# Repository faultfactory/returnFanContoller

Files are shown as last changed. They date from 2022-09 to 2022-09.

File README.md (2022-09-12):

# returnFanContoller

### Problem: 

My house has an issue with stratification in the summer, requiring us to leave a fan in the stairwell. I saw this potentially coming from talking to my neighbors and in addition to good insulation on the roof deck, I also installed a return air duct on the 2nd floor (which it did not have).  This duct is very high in the room and with a proper draw should evacuate hot air in the room quickly with the right amount of negative pressure applied. Because the return ducts in the house start with a (very poorly sealed) run of panning through joist bays and the duct takes a circuitous path upstairs, I am confident I am getting very little, if any draw from the return duct I connected to the 2nd floor.  To remedy this I have purchased a [Fantech ProAir EC-6](https://shop.fantech.net/en-US/prioair--6--ec--inline--duct--fan/p96222#!) I chose this because I would rather not play around with dampers if I can help it.  My furnace is not intended to integrate  with any sort of external fan, nor is my thermostat (nest... maybe 2nd gen?). 

### Goals: 

1. Log the activity of the 24VAC thermostat signals coming from the Nest. Also log the blower fan speeds and some relevant temperatures. 
2. Activate the booster fan when the furnace fan runs.
3. Monitor a temp sensor on the second floor and activate both the furnace and booster fan when the temperature differential exceeds a threshold. 

~~This repostitory consists of the code for the controller which will run on a raspberry pi. Schematics / BOM  will be on a separate hackaday.io project when time permits.~~

This project has been completed and I am in the process of documenting it. Overwhelming success. However, it was exceptionally difficult to get a proper PWM generated out of the raspberry pi and over time it just became more trouble than it was worth to stay with that platform. I've moved the effort to an Arduino which worked fine. I am still going to attempt to add some of the bells and whistles I wanted earlier but for now it works great.

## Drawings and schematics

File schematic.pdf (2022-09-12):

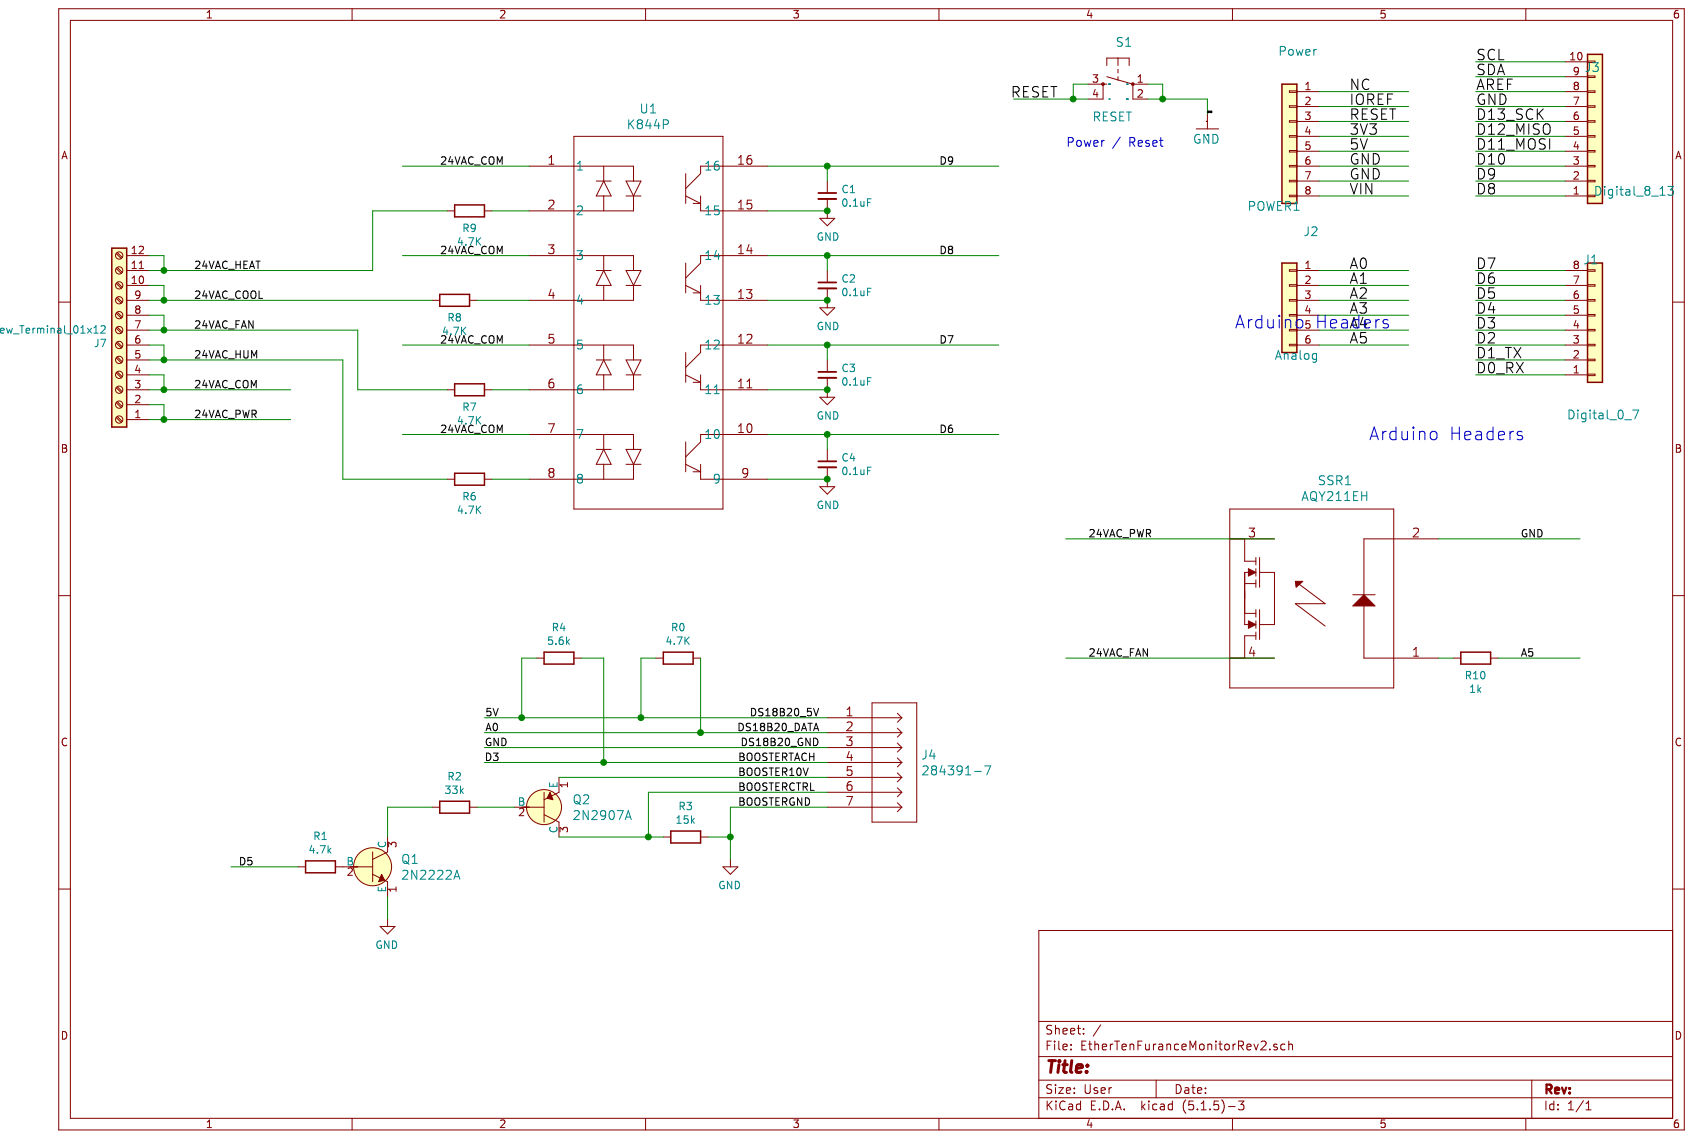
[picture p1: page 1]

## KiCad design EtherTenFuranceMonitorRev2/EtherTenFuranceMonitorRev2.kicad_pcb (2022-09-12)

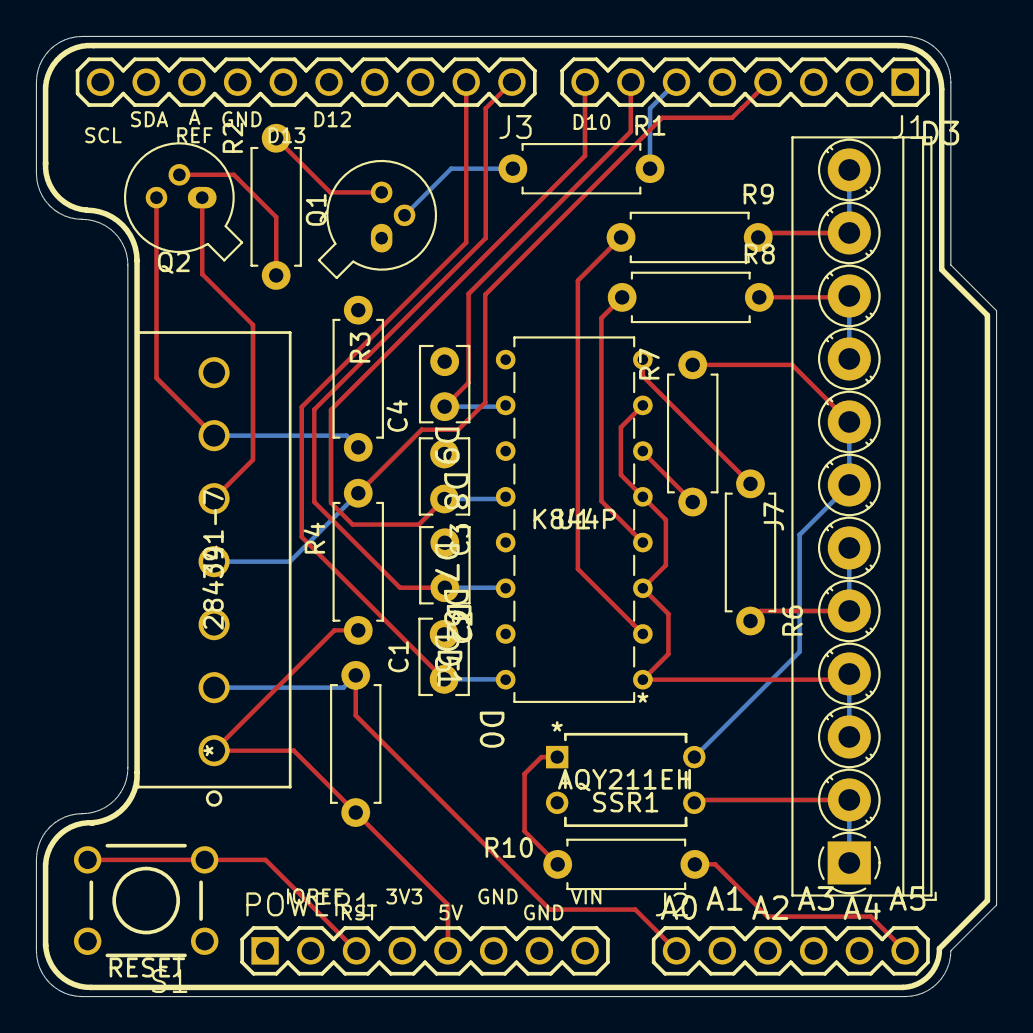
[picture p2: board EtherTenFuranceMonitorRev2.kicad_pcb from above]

Board: 2 copper layers, 53.3 x 53.3 mm, 25 parts (0 on the bottom side), 27 nets.

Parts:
C1, C2, C3, C4: 0.1uF; C_Rect_L4.0mm_W2.5mm_P2.50mm
J1: Digital_0_7; 1X08
J2: Analog; 1X06
J3: Digital_8_13; 1X10
J4: 284391-7
J7: Screw_Terminal_01x12; TerminalBlock_Phoenix_PT-1,5-12-3.5-H_1x12_P3.50mm_Horizont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
POWER1: Power; 1X08
Q1: 2N2222A; TO-18-3
Q2: 2N2907A; TO-18-3
R0, R6, R7, R8, R9: 4.7K; R_Axial_DIN0207_L6.3mm_D2.5mm_P7.62mm_Horizontal
R1: 4.7k; R_Axial_DIN0207_L6.3mm_D2.5mm_P7.62mm_Horizontal
R2: 33k; R_Axial_DIN0207_L6.3mm_D2.5mm_P7.62mm_Horizontal
R3: 15k; R_Axial_DIN0207_L6.3mm_D2.5mm_P7.62mm_Horizontal
R4: 5.6k; R_Axial_DIN0207_L6.3mm_D2.5mm_P7.62mm_Horizontal
R10: 1k; R_Axial_DIN0207_L6.3mm_D2.5mm_P7.62mm_Horizontal
S1: RESET; TACTILE-PTH
SSR1: AQY211EH
U1: K844P

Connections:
/5V: J4.1, POWER1.5, R0.1, R4.1
/24VAC_COM: J7.3, J7.4, U1.1, U1.3, U1.5, U1.7
/24VAC_COOL: J7.9, J7.10, R8.2
/24VAC_FAN: J7.7, J7.8, R7.2, SSR1.4
/24VAC_HEAT: J7.11, J7.12, R9.2
/24VAC_HUM: J7.5, J7.6, R6.2
/24VAC_PWR: J7.1, J7.2, SSR1.3
/A0: J2.1, J4.2, R0.2
/A5: J2.6, R10.2
/BOOSTER10V: J4.5, Q2.1
/BOOSTERCTRL: J4.6, Q2.3, R3.2
/BOOSTERTACH: J1.4, J4.4, R4.2
/D5: J1.6, R1.2
/D6: C4.1, J1.7, U1.10
/D7: C3.1, J1.8, U1.12
/D8: C2.1, J3.1, U1.14
/D9: C1.1, J3.2, U1.16
/RESET: POWER1.3, S1.3, S1.4
GND: C1.2, C2.2, C3.2, C4.2, J3.7, J4.3, J4.7, POWER1.6, POWER1.7, Q1.1, R3.1, S1.1, S1.2, SSR1.2, U1.9, U1.11, U1.13, U1.15
unnamed: Q1.2, R1.1
unnamed: Q1.3, R2.2
unnamed: Q2.2, R2.1
unnamed: R6.1, U1.8
unnamed: R7.1, U1.6
unnamed: R8.1, U1.4
unnamed: R9.1, U1.2
unnamed: R10.1, SSR1.1

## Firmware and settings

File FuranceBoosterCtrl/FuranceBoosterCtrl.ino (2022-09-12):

#define ETL_NO_STL
#include <Arduino.h>
#include <Embedded_Template_Library.h>
#include <etl/flat_map.h>

#define FAN_PWM_OUTPUT 5
#define OPTO_PIN_HEAT 9
#define OPTO_PIN_COOL 8
#define OPTO_PIN_FAN 7
#define OPTO_PIN_HUM 6
#define FANSPEED_INPUT_PIN 3
#define SSR_OUT_PIN A5
#define SD_CS = 4;
#define WIZ_CS = 10;

float fanSpeed;
int fanCmdIdle = 70;
int fanCmdPreBurst = 110; //Lower to gradually increase speed vs overshoot. 
int fanCmdOn = 150;

int fanStatePrior;
int fanStateNow; 
int fanCommandPWM;
unsigned long fanOnTime; 
unsigned long fanOffTime; 
const unsigned long burstLength = 10000;
bool tempError = false;

volatile unsigned long prevTime = 0;
volatile unsigned long edgeTime = 0;
volatile unsigned long pulseCounter = 0;
volatile bool newPulse = false;

byte mac[] = { 0xDE, 0xAD, 0xBE, 0xEF, 0xFE, 0xED };    
byte myIp[] = { 192, 168 , 1 , 19 };

enum HVACState
{
   UNKNOWN,
   SIGNAL_LOW,
   SIGNAL_HIGH
};

enum HVACSignal
{
   FURNACE_FAN,
   HEAT,
   COOL,
   HUMIDIFY
};

etl::flat_map<HVACSignal,HVACState,4> stateMap;
etl::flat_map<HVACSignal,bool,4> activeMap;
etl::flat_map<HVACSignal,int,4> pinMap;



HVACState getHVACState(HVACSignal signal)
{
   if(activeMap[signal])
   {
       int pinState = digitalRead(pinMap[signal]);
       if(pinState == LOW)
       {
           return SIGNAL_HIGH;
       }
       if(pinState == HIGH)
       {
           return SIGNAL_LOW;
       }
       return UNKNOWN;
   }
   else
   {
       return UNKNOWN;
   }
   return UNKNOWN;
}

void updateHVACStates()
{
  for(auto& sig : stateMap)
  {
    sig.second = getHVACState(sig.first);
  }
}

void updateFanSpeed()
{
  unsigned long timing = calculatePulseTiming();
  Serial.print("timing: ");
  Serial.println(timing);
  if(timing == 0)
  {
    fanSpeed = 0.0f;
  }
  else
  {
    fanSpeed = 60.0f * 1000000.0f/(float(timing));
  }
}

void measureTimingViaISR()
{
  noInterrupts();
  prevTime = 0;
  edgeTime = 0;
  pulseCounter = 0;
  newPulse = false;
  interrupts();
  auto now = millis();
  auto start = now;
  while (now < start + 1000)
  {
    now = millis();
  }
  Serial.print("Pulse Counter:  ");
  Serial.println(pulseCounter);
}

unsigned long calculatePulseTiming()
{
  measureTimingViaISR();
  // Serial.println(prevTime);
  // Serial.println(edgeTime);
  // Serial.println(pulseCounter);
  if (newPulse == false || pulseCounter == 1)
  {
    return 0;
  }
  else
  {
    noInterrupts(); 
    unsigned long deltaTime = edgeTime - prevTime;
    pulseCounter = 1;
    newPulse = false;
    interrupts();
    return deltaTime;
  }
}

int leftOfDecimal(float value)
{
  int leftValues = 1; 
    while(value/10 > 0)
    {
      value /=10;
      leftValues++;
    }
    return leftValues;
}



void updateFanCommand()
{
  fanStateNow = stateMap[FURNACE_FAN];
  Serial.print("Fan State");
  Serial.println(fanStateNow);
  if(fanStateNow!=SIGNAL_HIGH)
  {
    fanCommandPWM = fanCmdIdle;
  }
  else
  {
    if(fanStateNow!=fanStatePrior)
    { 
      fanOnTime = millis();
      fanCommandPWM = fanCmdPreBurst;
    }
    else
    {
      if(millis() > (fanOnTime + burstLength))
      {
        fanCommandPWM = fanCmdOn;
      }
    }
  }  

  analogWrite(FAN_PWM_OUTPUT,fanCommandPWM);
  delay(50);
  fanStatePrior = fanStateNow;
  Serial.println(fanCommandPWM);
}

void setup()
{ 
  Serial.begin(9600);
  
  pinMode(2, INPUT_PULLUP);
  pinMode(SSR_OUT_PIN, OUTPUT);
  
  // Set status for opto input pins
  pinMode(pinMap[FURNACE_FAN],INPUT_PULLUP);
  pinMode(pinMap[HEAT],INPUT_PULLUP);
  pinMode(pinMap[COOL],INPUT_PULLUP);
  pinMode(pinMap[HUMIDIFY],INPUT_PULLUP);
  // Set status for SSR output Pin
  digitalWrite(SSR_OUT_PIN, LOW);  
  // Set SDCard off. 
  
  // Attach interrupt to pin for measuring Fanspeed
  pinMode(FANSPEED_INPUT_PIN, INPUT_PULLUP);
  attachInterrupt(digitalPinToInterrupt(FANSPEED_INPUT_PIN), ISR1, FALLING);

  
   stateMap.insert(etl::pair<HVACSignal,HVACState>{FURNACE_FAN,UNKNOWN});
   stateMap.insert(etl::pair<HVACSignal,HVACState>{HEAT,UNKNOWN});
   stateMap.insert(etl::pair<HVACSignal,HVACState>{COOL,UNKNOWN});
   stateMap.insert(etl::pair<HVACSignal,HVACState>{OVERRIDE,UNKNOWN});
   
   activeMap.insert(etl::pair<HVACSignal,bool>{FURNACE_FAN,true});
   activeMap.insert(etl::pair<HVACSignal,bool>{HEAT,true});
   activeMap.insert(etl::pair<HVACSignal,bool>{COOL,true});
   activeMap.insert(etl::pair<HVACSignal,bool>{OVERRIDE,false});

   pinMap.insert(etl::pair<HVACSignal,int>{FURNACE_FAN,OPTO_PIN_FAN});
   pinMap.insert(etl::pair<HVACSignal,int>{HEAT,OPTO_PIN_HEAT});
   pinMap.insert(etl::pair<HVACSignal,int>{COOL,OPTO_PIN_COOL});
   pinMap.insert(etl::pair<HVACSignal,int>{OVERRIDE,OPTO_PIN_HUM});
  
}

void loop()
{
   
  updateHVACStates();
  updateFanSpeed();
  updateFanCommand();

  Serial.print("Fan Speed: ");
  Serial.println(fanSpeed);
  delay(5000);

}


void ISR1()
{
  prevTime = edgeTime;
  edgeTime = micros();
  pulseCounter++;
  newPulse = true;
}
  

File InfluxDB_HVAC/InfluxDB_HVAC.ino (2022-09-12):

#define ETL_NO_STL
#define HVAC_SHIELD_DEBUG_SERIAL
#include <Arduino.h>
#include <Embedded_Template_Library.h>
#include <etl/flat_map.h>
#include <Ethernet.h>
#include "src/EthernetSimpleInfluxDB/SimpleInfluxDB.h"
#include <DallasTemperature.h>
#include "src/HVACShield/HVACShield.h"

#define INFLUX_DEBUG_SERIAL

#define SD_CS 4
#define WIZ_CS 10

const String inf_org = "Home";
const String inf_bucket = "tests";

const unsigned int fanCmdIdle = 70;
const unsigned int fanCmdPreBurst = 110;
const unsigned int fanCmdOn = 150;


int fanStatePrior;
int fanStateNow; 
unsigned int fanCommandPWM;
unsigned long fanOnTime; 
unsigned long fanOffTime; 
const unsigned long burstLength = 10000;

byte mac[] = {0xDE, 0xAD, 0xBE, 0xEF, 0xFE, 0xED}; // max address for ethernet shield
IPAddress controllerIP(192, 168, 1, 46);
EthernetClient client;

// INFLUX SETUP - make your own configuration file
#include "src/InfluxConfig/conf.h"
SimpleInfluxClient iClient(&client,INFLUX_API_TOKEN,INFLUX_SERVER_AND_PORT);
byte server[] = { 192, 168, 1, 25 };

HVACShield hvacShield;

void updateFanCommand()
{
  fanStateNow = hvacShield.getHVACState(FURNACE_FAN);
  Serial.print(F("Fan State"));
  Serial.println(fanStateNow);
  if(fanStateNow!=SIGNAL_HIGH)
  {
    fanCommandPWM = fanCmdIdle;
  }
  else
  {
    if(fanStateNow!=fanStatePrior)
    { 
      fanOnTime = millis();
      fanCommandPWM = fanCmdPreBurst;
    }
    else
    {
      if(millis() > (fanOnTime + burstLength))
      {
        fanCommandPWM = fanCmdOn;
      }
    }
  }  

  hvacShield.setFanCommand(fanCommandPWM);
  delay(50);
  fanStatePrior = fanStateNow;
  Serial.println(fanCommandPWM);
}


void httpResponseToSerialOut()
{
  delay(10);
  #ifdef INFLUX_DEBUG_SERIAL
  Serial.println("Response:  ");
  while (client.available()) 
  {
      char c = client.read();
      Serial.print(c);
  }
  Serial.println();
  #endif
}

void sendHVACStatus() {
    Point furnaceData("Furnace24VStatus");
    furnaceData.addField("Fan",(int)hvacShield.getHVACState(FURNACE_FAN));
    furnaceData.addField("Heating",(int)hvacShield.getHVACState(HEAT));
    furnaceData.addField("Cooling",(int)hvacShield.getHVACState(COOL));
    furnaceData.addField("Humidify",(int)hvacShield.getHVACState(HUMIDIFY));
    furnaceData.addField("Override",(int)hvacShield.getHVACState(OVERRIDE));
    iClient.sendPoint(inf_org,inf_bucket,furnaceData);
    httpResponseToSerialOut();
}

void sendBlowerData() {
    Point blowerData("BlowerStatus");
    blowerData.addField("FanRPM",(float)hvacShield.getFanSpeed());
    blowerData.addField("FanCommandPWM",(int)(100*fanCommandPWM/255));
    iClient.sendPoint(inf_org,inf_bucket,blowerData);
    httpResponseToSerialOut();
}

void sendTempData() {
    Point tempData("Temperatures");
    tempData.addField("Upstairs",hvacShield.getRemoteTemp());
    tempData.addField("GroundFloor",hvacShield.getBaseTemp());
    iClient.sendPoint(inf_org,inf_bucket,tempData);
    httpResponseToSerialOut();
}

/*
     MAIN LOGIC
*/

void setup() {
  hvacShield = HVACShield();
  Serial.begin(9600);
  Serial.println("Starting Ethernet");
  Ethernet.begin(mac, controllerIP);
  Serial.println("Ethernet Started.");
  // Set SDCard off. 
  pinMode(SD_CS, OUTPUT);
  digitalWrite(SD_CS, HIGH);
  pinMode(2, INPUT_PULLUP);
  DeviceAddress upstairsThermometer = { 0x28, 0xFF, 0xC9, 0x1D, 0x85, 0x16, 0x03, 0xCF };
  DeviceAddress groundFloorThermometer   = { 0x28, 0xFF, 0x83, 0x32, 0x85, 0x16, 0x03, 0x71 };

  hvacShield.setRemoteTempAddr(upstairsThermometer);
  hvacShield.setBaseTempAddr(groundFloorThermometer);
  

}


void loop() {
  #ifdef INFLUX_DEBUG_SERIAL
 
  #endif

  hvacShield.updateHVACStates();
  hvacShield.updateTemperatureReadings();
  hvacShield.updateFanSpeed();
  updateFanCommand();

  Serial.print(F("Fan Speed: "));
  Serial.println(hvacShield.getFanSpeed());
  delay(1000);


  if (client.connect(server, 8086)) 
  {
    
    Serial.println("----------------Connected, Starting Loop-------------------");
    if (client.available()) 
    {
     httpResponseToSerialOut();
    }
    sendHVACStatus();
    delay(500);
    sendBlowerData();
    if(!hvacShield.isTempError())
    { 
      delay(500);
      sendTempData();
    }
    else
    {
      Serial.println(F("skipping temps"));
    }
  } 
  else 
  {
    // if you couldn't make a connection:
    Serial.println("connection failed");
  }    
  // close any connection before send a new request.
  // This will free the socket on the WiFi shield
  client.stop();
  delay(5000);
}

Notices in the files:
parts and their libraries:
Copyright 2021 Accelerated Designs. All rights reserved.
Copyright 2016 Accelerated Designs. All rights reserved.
